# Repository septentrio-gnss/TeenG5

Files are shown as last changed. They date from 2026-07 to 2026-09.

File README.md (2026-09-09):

# TeenG5

<p align="center">
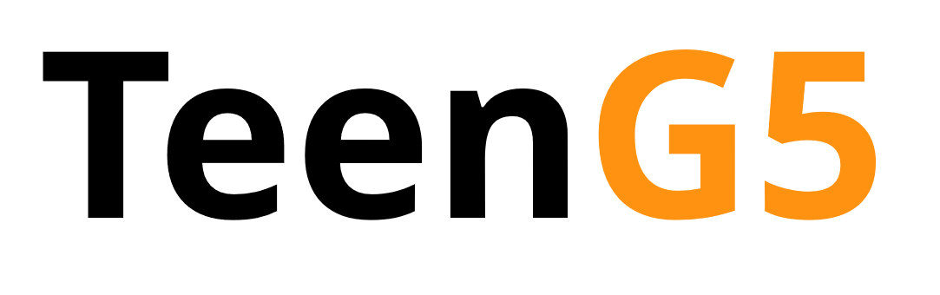
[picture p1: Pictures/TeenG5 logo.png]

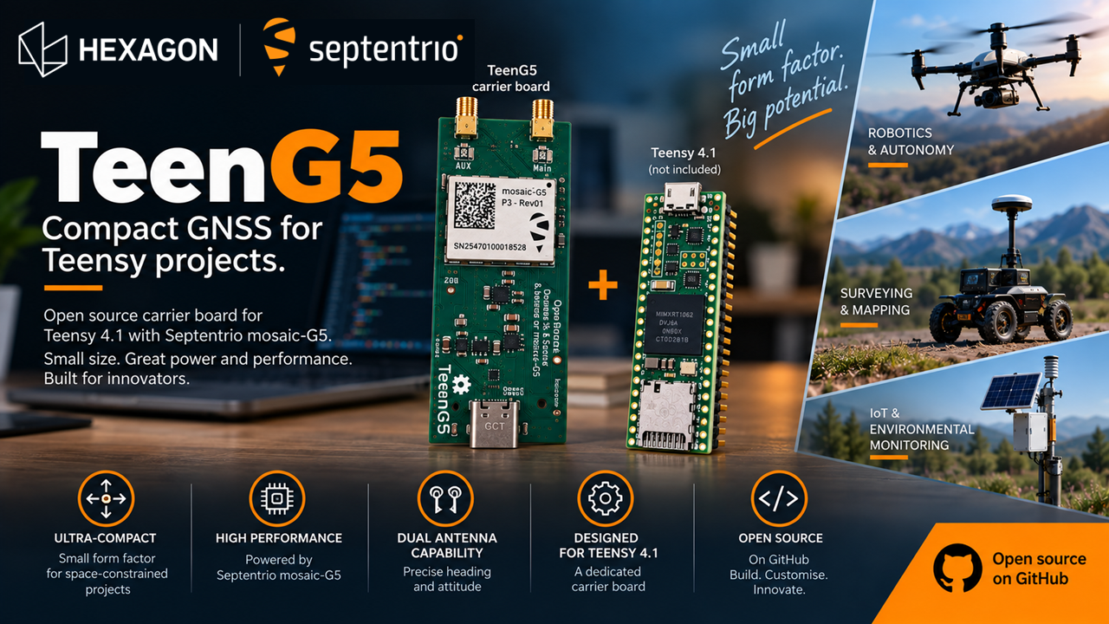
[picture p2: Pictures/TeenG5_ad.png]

</p>p

|TeenG5| Carrier board for Teensy 4.1|
|---|---|
|Author|  [laekaz](https://github.com/laekaz)|
|Maintainer| [Septentrio gnss github user](githubuser@septentrio.com)|
|external website| https://github.com/septentrio-gnss/TeenG5  |
|License| [CC BY-SA 4.0](https://creativecommons.org/licenses/by-sa/4.0/) and [open source](https://www.oshwa.org/definition/) |

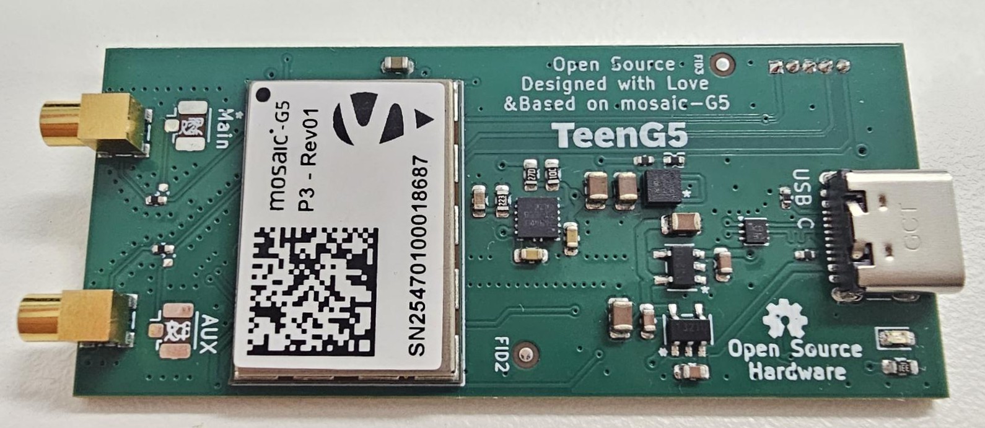
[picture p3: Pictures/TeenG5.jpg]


## Table of Content

* [What is TeenG5](#what-is-teeng5)
    * [What is the Teensy 4.1?](#what-is-the-teensy-41)
    * [What is a Carrier Board for Teensy 4.1?](#what-is-a-carrier-board-for-teensy-41)
    * [Produce Yourself?](#produce-yourself)
            * [Do I Need to Source Special Components for Producing This Board?](#do-i-need-to-source-special-components-for-producing-this-board)
    * [What is a mosaic-G5 Module?](#what-is-a-mosaic-g5-module)
        * [Other mosaic-G5 Versions](#other-mosaic-g5-versions)
    * [Who is Septentrio?](#who-is-septentrio)
    * [Deliverables](#deliverables)
    * [Is the Project Open-Source?](#is-the-project-open-source)
* [Disclaimer](#disclaimer)
* [Documentation Sections](#documentation-sections)

## What is TeenG5
This is a compact carrier board that brings high precision GNSS (GPS) which integrates mosaic-G5 Septentrio's GNSS module with basic communications, allowing the system to receive signals from multiple GNSS constellations, such as GPS, Galileo, GLONASS, and BeiDo. The goal of the design is to simplify hardware prototyping and integration of the mosaic-G5 by taking advantage of the [Teensy 4.1's](https://www.pjrc.com/store/teensy41.html) high-performance microcontroller, extensive peripheral interfaces, and Arduino-compatible development ecosystem. This makes TeenG5 well suited for embedded applications such as robotics, autonomous vehicles, UAVs, precision agriculture, surveying, timing, and other systems that require low-latency GNSS processing without relying on an external computer.
 
The board can also operate as a standalone device when powered through its USB connector.

### What is the Teensy 4.1?
The [Teensy 4.1](https://www.pjrc.com/store/teensy41.html) is a compact, high-performance microcontroller development board based on the NXP i.MX RT1062 ARM Cortex-M7 processor running at 600 MHz. It offers 1 MB of RAM, 8 MB of onboard flash memory, a microSD card slot, USB host and device capabilities, Ethernet, and a wide range of digital, analog, and communication interfaces (UART, SPI, I²C, and CAN). Compatible with the Arduino IDE through Teensyduino software, it is well suited for robotics, real-time control,embedded systems, audio processing, data acquisition, and other performance-critical applications.

### What is a carrier board for Teensy 4.1?
A carrier board is a board that hosts a removable Teensy 4.1. The Teensy plugs into the board through two 24-pin headers and can be removed or replaced, while the carrier board integrates the Septentrio mosaic-G5 GNSS receiver, power management, and communication interfaces into a single embedded platform.

### Produce yourself?
You can use the design files, Bill of Materials from this project and contact your manufacturing company for production. In this project we used [JLCPCB](https://jlcpcb.com/) for producing the PCB and assembling it. We used JLCPCB because of its competitive pricing and component availability.

##### Do I need to source special components for producing this board?

Yes, Some components are not available through JLCPCB's standard parts library and must be supplied separately. however, if you are assembling the PCB by yourself, all components are available on DigiKey and clearly listed in the project's Bill of Materials. The mosaic GNSS module can be obtained from Digikey or directly from Septentrio. For larger production volumes, we recommend contacting the Septentrio sales team directly at [Septentrio Contact Page](https://www.septentrio.com/en/contact/ask-question)

### What is a mosaic-G5 module?
The mosaic-G5 is a compact GNSS receiver from Septentrio, engineered for high reliability and precise positioning. It integrates the latest multi-band, multi-constellation GNSS technology, providing accurate positions while minimizing power consumption. The receiver can access signals from all major GNSS constellations, including GPS, Galileo, GLONASS, and BeiDou.

#### Other mosaic-G5 versions
Different versions of the mosaic-G5 are available to suit various applications, as summarized below:

| Features | [mosaic-G5 P1](https://www.septentrio.com/en/products/gnss-receivers/gnss-receiver-modules/mosaic-g5-p1) | [mosaic-G5 P3](https://www.septentrio.com/en/products/gnss-receivers/gnss-receiver-modules/mosaic-G5-P3) | [mosaic-G5 P3H](https://www.septentrio.com/en/products/gnss-receivers/gnss-receiver-modules/mosaic-G5-P3H) |[mosaic-G5 P6](https://www.septentrio.com/en/products/gnss-receivers/gnss-receiver-modules/mosaic-G5-P6) | [mosaic-G5 P8](https://www.septentrio.com/en/products/gnss-receivers/gnss-receiver-modules/mosaic-g5-p8) |
|---|---|---|---|---|---|
| Functionality|High-precision positioning |High-precision positioning |Positioning + Heading|Positioning + Heading | Positioning + Heading|
| Use case |Robotics (e.g robotic mowers), GIS devices |UAV, Commercial mowers, Industrial Robotics, Survey, Marine navigation | Marine navigation, Machine control, Autonomous vehicles,  Survey | Autonomous vehicles, Marine navigation, Machine control, Survey | High-end autonomous systems, Robotics, Marine navigation, Survey, Machine control | 
| GNSS bands | Triple-band  | Quad-band | Quad-band |Quad-band |Quad-band  |
| RTK support  | Yes | Yes | Yes |Yes |Yes |
| Dual antenna | No |  No | Yes |Yes |Yes |
| Heading | NO | No | Yes |Yes |Yes |

### Who is Septentrio?
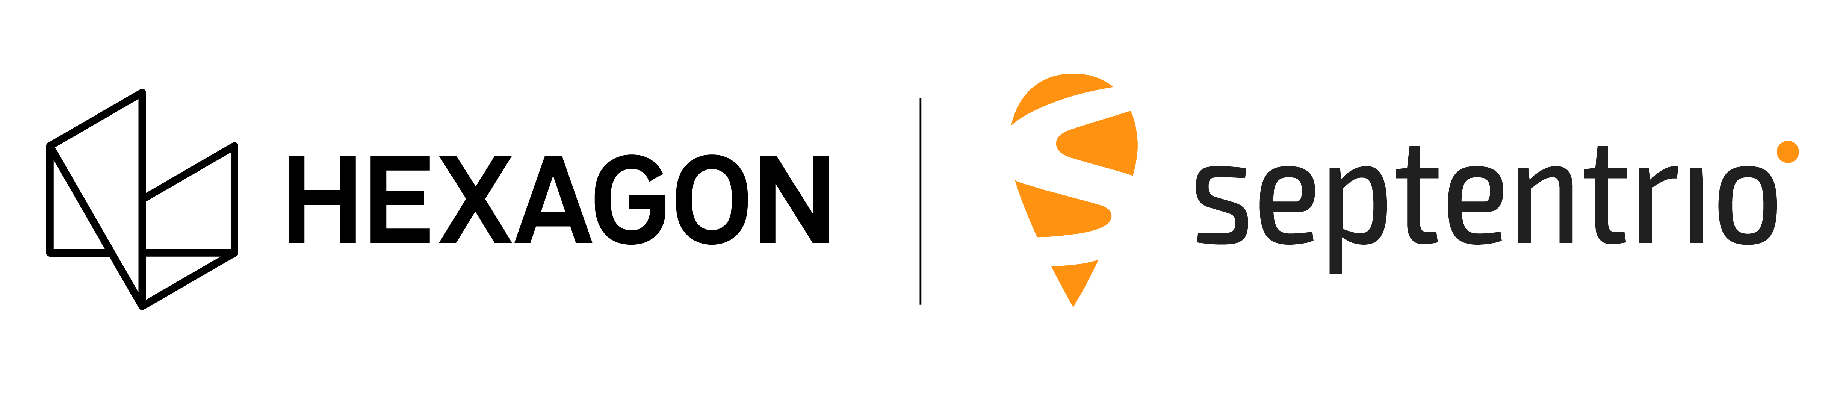
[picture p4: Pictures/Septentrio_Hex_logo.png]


Septentrio is a leading company that designs, manufactures and sells high precision and multi-frequency GPS/GNSS receivers for demanding applications. Septentrio products are used in different industries including automotive, marine, construction, rail, machine control, logistics, precision agriculture, geographic information systems (GIS), Unmanned aerial vehicles (UAVs), surveying, mapping and scientific development. Septentrio’s receivers constantly deliver accurate and precise GNSS positioning scalable to centimetre-level and designed to perform perfectly in challenging environments. 

Septentrio's technology offers high accuracy and reliability thanks to advanced GNSS signal-processing algorithms as well as [Advanced interference Monitoring and Mitigation (AIM+)](https://www.septentrio.com/en/learn-more/advanced-positioning-technology/aim-anti-jamming-protection) This protects your application against jamming (RF interference) and spoofing (malicious attacks).

For more information about Septentrio products go to [**https://www.septentrio.com/**](https://web.septentrio.com/GH-SSN-home).

### Deliverables
This project provides the following deliverables for system integrators and hardware designers developing solutions based on Septentrio's mosaic-G5 modules.

|Files |Description |
|---|---|
|  [G5_Teensy.kicad_pro](./Kicad/TeenG5/G5_Teensy.kicad_pro) |KiCad project |
| [G5_Teensy.kicad_pcb](./Kicad/TeenG5/G5_Teensy.kicad_pcb) | KiCad layout |
|  [G5_Teensy.kicad_sch](./Kicad/TeenG5/G5_Teensy.kicad_sch)  |KiCad schematic |
| [TeenG5 3D.step](./Kicad/TeenG5%203D/teenG5%203D.step) | TeenG5 3D|
| [mosaic-G5.STEP](./Kicad/mosaci-G5/mosaic-G5.STEP)  |mosaic-G5 3D |
| [LGA54_MOSAIC-MINI_SEP.kicad_mod](./Kicad/mosaci-G5/LGA54_MOSAIC-MINI_SEP.kicad_mod)  |mosaic-G5 footprint |
|  [BOM](./Kicad/BOM.xlsx) | TeenG5 Bill of Materials |
### Is the project open-source?
Yes, We made this open source so you can tinker, adapt, and create. If you are building your own robotics project, a spin-off device, or integrating GNSS into a larger system, this is a great starting point.

Open source here means:
* All files fully editable
* Freedom to modify, remix, and innovate
* You can sell your version. No -NC limitations
* May require attribution
* Build on our work, push it further, and even make money doing it

More info about licensing can be found here: [CC BY-SA 4.0](https://creativecommons.org/licenses/by-sa/4.0/) and [open source](https://www.oshwa.org/definition/)

## Disclaimer
This project is **offered as-is**. The main interfaces have been tested, but the design has not been fully checked or approved by the author or Septentrio. You are responsible for how you use it in your own projects. For guidance on working with Septentrio’s GNSS mosaic-G5 modules, we suggest reaching out to Septentrio directly.

Support website: https://www.septentrio.com/en/support
## Documentation Sections

This project provides two main documentation sections:

- **[TeenG5 User Documentation](./TeenG5%20User%20Documentation.md)**  
  Contains information for users on how to install, configure, and use the TeenG5.

- **[TeenG5 Design Documentation](./TeenG5%20Design%20Documentation.md)**  
  Intended for hardware designers who want to understand, customize, or modify the reference design of the TeenG5.

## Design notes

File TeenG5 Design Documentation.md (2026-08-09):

# TeenG5 Design Documentation

This section describes the design principles and architecture of the TeenG5 in depth.

## Table of Content

* [Design Overview](#design-overview)
* [mosaic-G5 Pinout](#mosaic-g5-pinout)
* [Power Sources](#power-sources)
* [Antennas](#antennas)
    * [Antenna Connectors](#antenna-connectors)
    * [First Antenna](#first-antenna)
    * [Second Antenna](#second-antenna)
* [Teensy 4.1 Serial](#teensy-41-serial)
* [Reset Input](#reset-input)
* [USB-C](#usb-c)
* [LEDs, Events and PPSO](#leds-events-and-ppso)
* [Clock Frequency Reference](#clock-frequency-reference)
* [Further Improvements](#further-improvements)

## Design Overview

The TeenG5 is a four-layer Printed Circuit Board (PCB) designed to mount directly a Teensy 4.1 onto it. The top and bottom layers are used for both signal and power routing. The first internal layer serves as a ground (GND) plane, while the first internal layer is primarily used as a 3.3 V power plane, with limited routing for additional connections where required.

The design as components on the **Top** and **bottom** side of the PCB board. The design uses Surface-Mount Devices (SMDs). throughout, except for the external connector.

The TeenG5 was designed using [KiCad](https://www.kicad.org/download/), an open-source Electronic Design Automation (EDA) suite. In addition to its schematic capture and PCB layout capabilities, KiCad includes an integrated 3D viewer that provides a realistic representation of the assembled board.

The schematic diagram is shown below. For improved readability and access to complete design details, refer to the PDF version of the [schematic]().

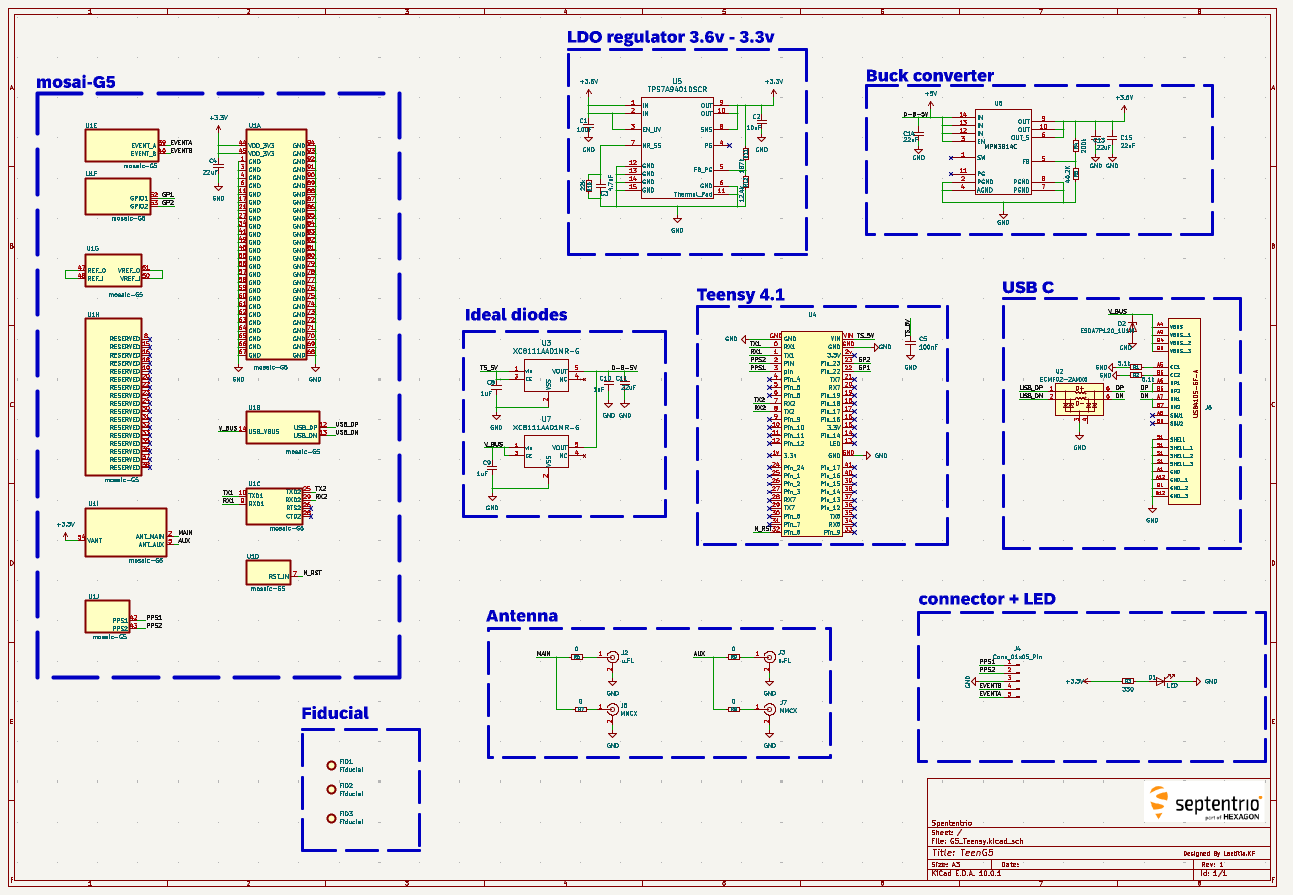
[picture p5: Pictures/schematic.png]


The board layout without the copper pour.

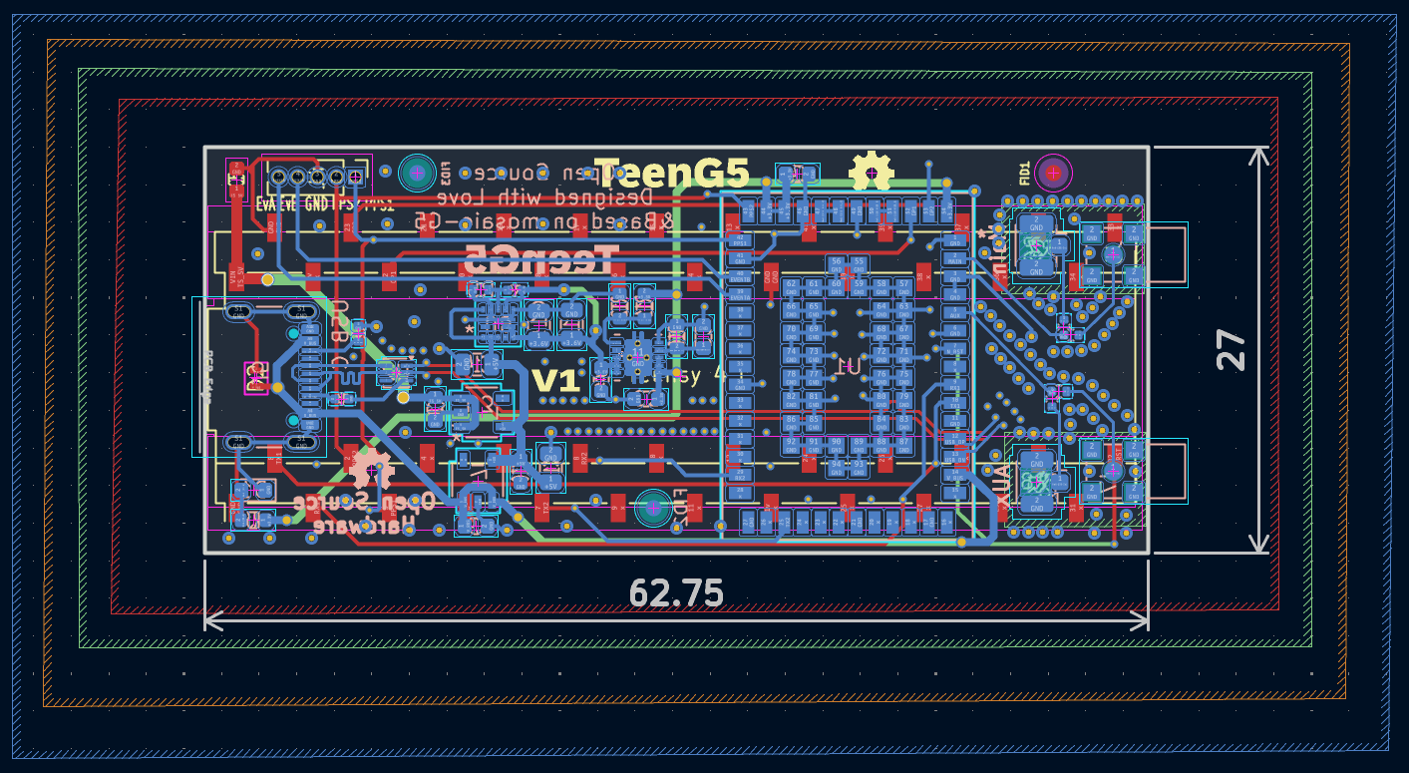
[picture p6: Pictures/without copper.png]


The board layout with the copper pour

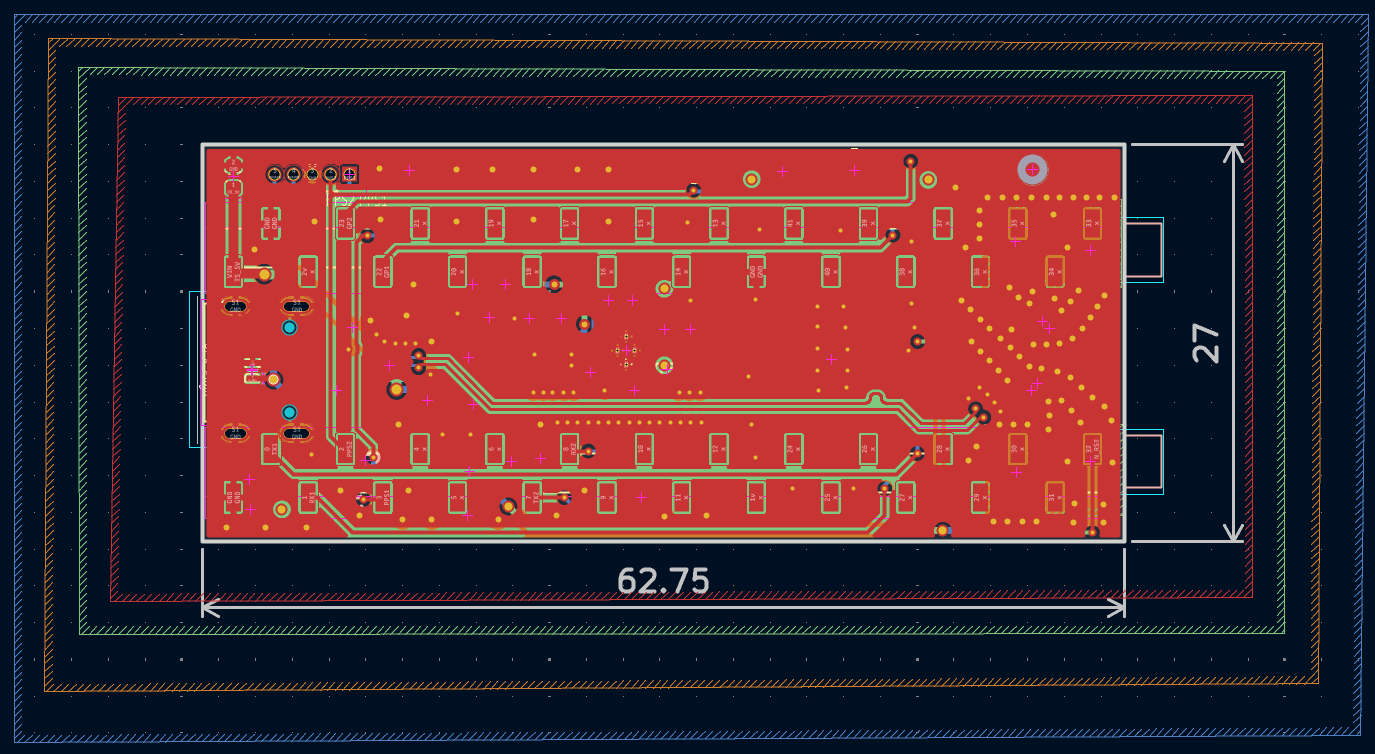
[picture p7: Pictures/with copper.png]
            

Layout layer descriptions:

|Layer|Description|
|---|---|
|Layer 1| Red traces, copper pour connected to GND |
|Layer 2| Green traces, copper pour connected to 3.3 V|
|Layer 3| Solid GND plane  |
|Layer 4| Blue traces, copper pour connected to GND|

A bottom and top 3D view of the TeeenG5, featuring electronic components.

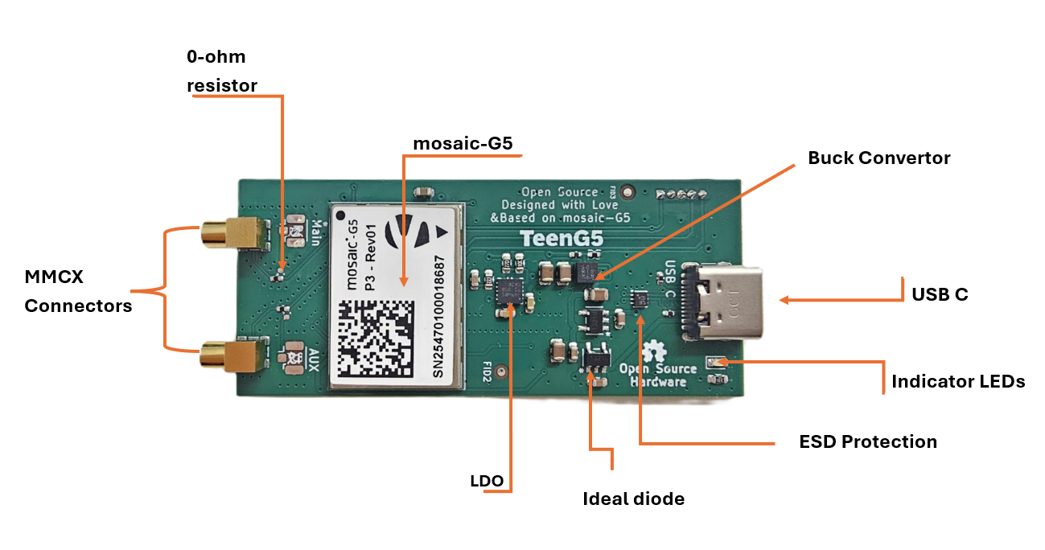
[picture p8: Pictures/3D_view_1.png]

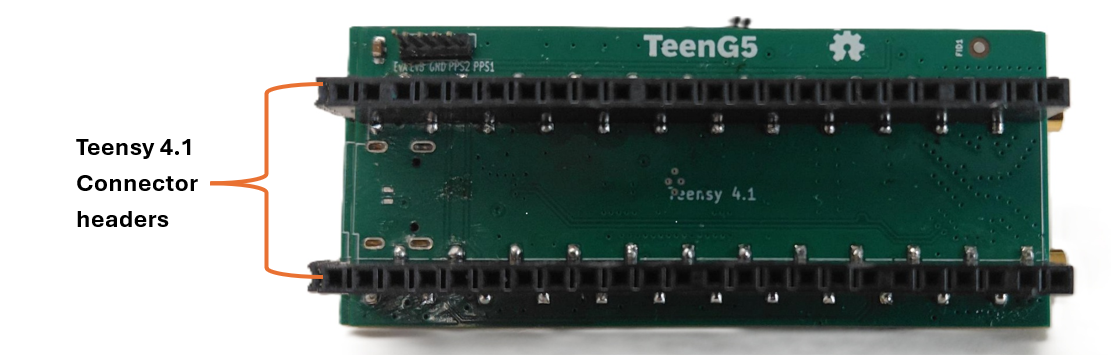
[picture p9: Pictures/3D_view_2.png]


## mosaic-G5 Pinout
The Septentrio mosaic-G5 is the core of the TeenG5 board. It is a 22.8 x 16.4 mm compact GNSS module of 94 pins with a weight of 2.2 g. Complete information on mosaic-G5 connections can be found in the [Hardware Manual](https://www.septentrio.com/en/products/gnss-receivers/gnss-receiver-modules/mosaic-G5-P3H).

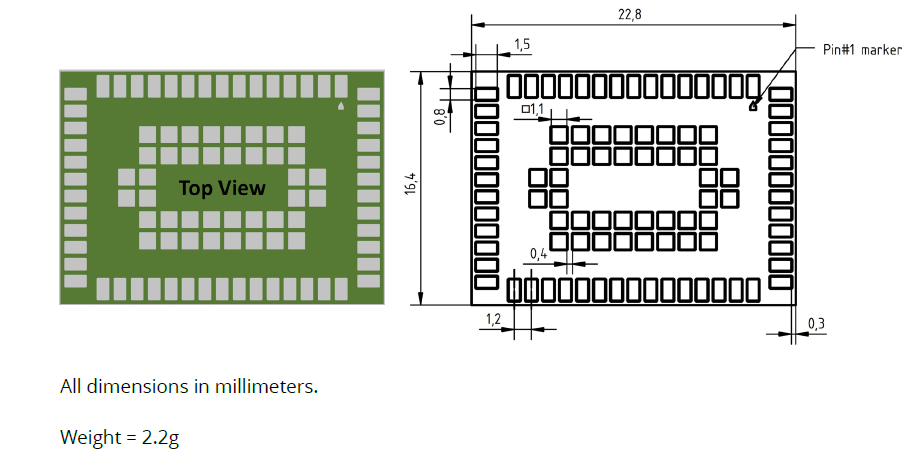
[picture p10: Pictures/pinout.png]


The symbol, footprint and 3D model of mosaic-G5 can be found [here](https://app.ultralibrarian.com/details/536b89de-4b22-11f0-b69d-024899f9dfe1/Septentrio/MOSAIC-G5-P3)

## power sources

The TeenG5 has 2 ways for powering the board; Teensy 4.1 VCC pin and USB-C. The mosaic-G5 module itself runs on 3.3V, thus a buck converter(MPM3814C) is used to regulate the voltage from 5V to 3.7V and an LDO voltage regulator is used to filter the switching noise from the buck converter and to regulate the voltage from 3.7 to 3.3volts(TPS7A9401DSCR). Teensy 4.1 VCC pin and USB-C already provide 5V.

 **WARNING:** Applying voltages higher than 5 V to the **VANT** may damage the module

The ideal diodes (**XC8111AA01MR-G**) are used to ensure one-way current flow. Decoupling capacitors (1 µF) are used according to the datasheet. The following figure shows the power section of the schematic.

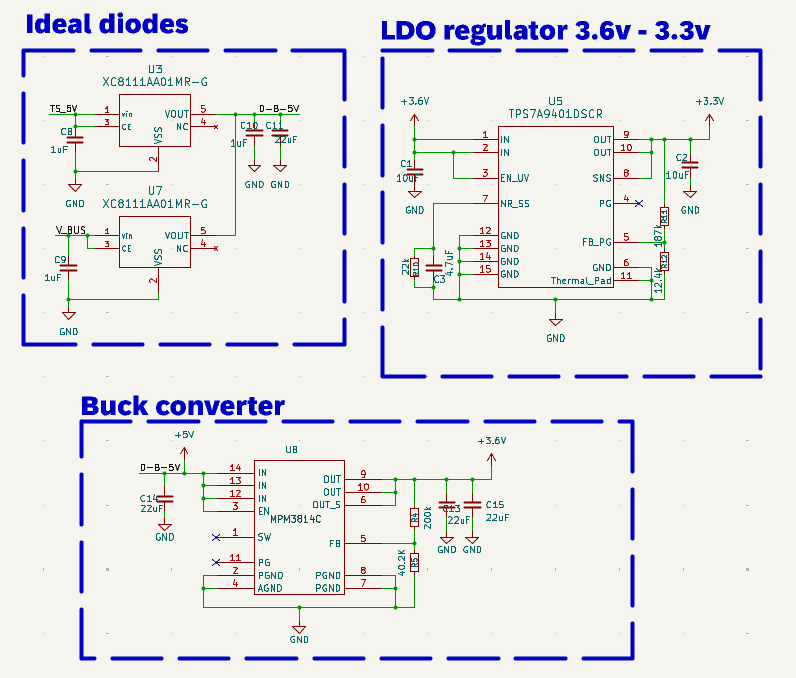
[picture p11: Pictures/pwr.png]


In the figure above:
1. Buck converter(MPM3814C).
2. Voltage regulator (TPS7A9401DSCR).
3. Teensy 4.1 power source (5V pins).
4. Micro USB power source.

## Antennas 
The mosaic-G5 P3H is a dual-antenna while the mosaic-G5 P3 is a single-antenna both of these modules are compatible with the PCB board however, when connecting the mosaic-G5 P3 you only connect the main antenna connector and leave the auxiliary unconnected. Both the antenna pins are not ESD-protected or biased in the schematics because all is done inside the module. 

The following figure shows the antenna section of the schematic.

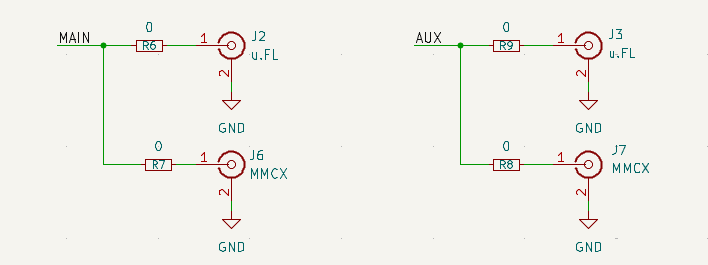
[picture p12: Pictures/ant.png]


### Antenna Connectors

### First Antenna

The first U.FL antenna J2 is directly connected to a 0 ohm resistor and the first MMCX antenna J6 is also connected to a 0 ohm resistor and they are both connected to the main mosaic-G5 pin.
The DC voltage of the main antenna connection is supplied from the mosaic-G5's VANT pin.

The input impedance of the RF line is 50 Ohms. Thus, antenna trace should have a characteristic impedance (Zo) of 50 Ohms. To determine the proper impedance for the antenna traces for RF signal routing, calculations were performed with the [JLCPCB Impedance Calculator](https://jlcpcb.com/pcb-impedance-calculator)(recommended if you are using JLCPCB as manufacturer) or can use freeware [Saturn PCB toolkit](https://saturnpcb.com/pcb_toolkit). The trace parameters used in the calculation were based on the specifications of the selected PCB manufacturer. Calculations determined that a trace width of 0.1725 mm would provide an impedance of 50Ω to the RF antenna traces.

Having right characteristic impedance ensures reduced signal reflections in the opposite direction thus higher quality of signals. For uniform lines, characteristic impedance is dependent on trace length.

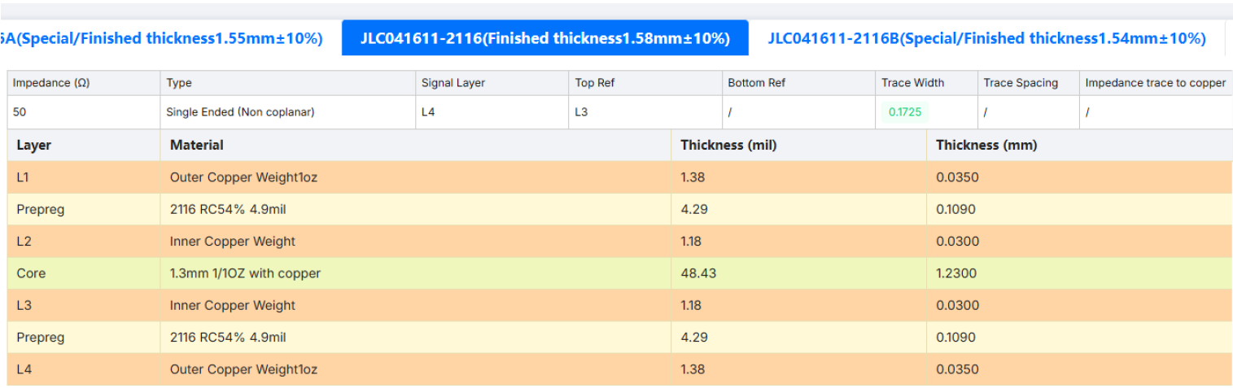
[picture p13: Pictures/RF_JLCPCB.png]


It is also important to stitch vias every few millimeters around the RF line for good ground coherence. Ground stitching vias help to protect line from interference.

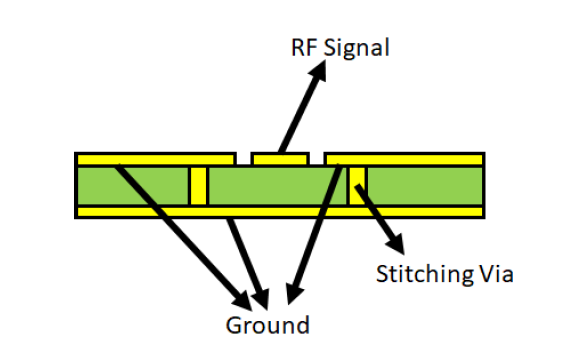
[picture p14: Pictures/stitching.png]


For more details on antennas and interference please refer to mosaic-G5's [Hardware Manual](https://www.septentrio.com/en/products/gnss-receivers?f%5B0%5D=type%3A604).

### second antenna

The second antenna is similar to the first antenna except when using a single antenna module like the mosaic-G5 P3, you do not need to assemble the the second antenna connector. 

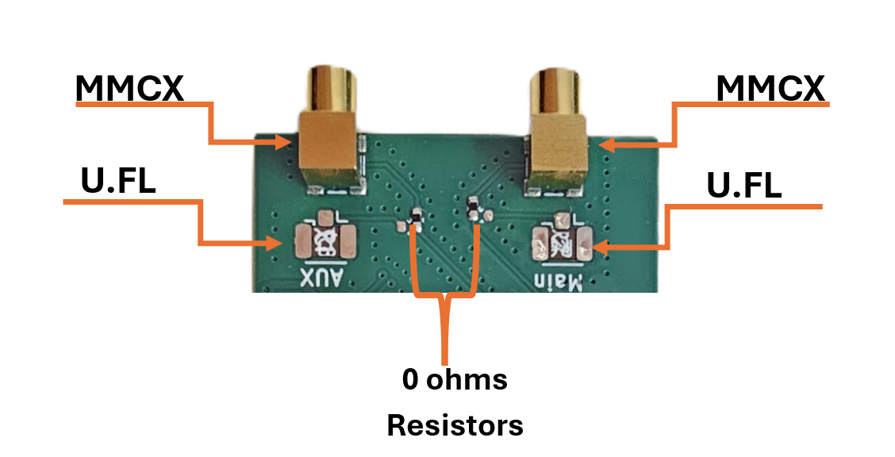
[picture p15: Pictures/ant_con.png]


## Teensy 4.1 serial

Serial communication between the mosaic-G5 and the Teensy 4.1 is implemented by connecting UART1 and UART2 connections of mosaic-G5 to Teensy 4.1 UART pins: TX (Pin 0, Pin 1) and RX (Pin 7, Pin 8). The mosaic-G5's TX is connected to the Teensy 4.1's RX while RX is connected to Teensy 4.1's TX for both UARTs.

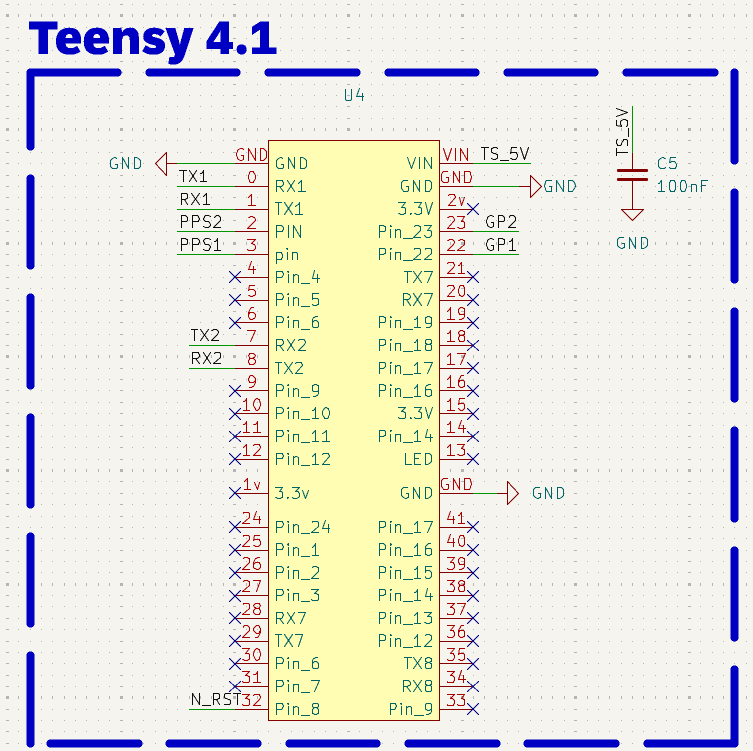
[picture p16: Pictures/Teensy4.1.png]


## Reset Input
The N_RST pin of mosaic-G5 is directly connected to Teensy 4.1 (Pin 32 in physical header). Refer to [Reset mosaic](#reset-mosaic-G5) in user documentation for more details.

## USB-C
To use mosaic-G5 as a USB device, the following pins of the module should be connected to a USB-C connector:



A common mode filter with ESD protection for USB 2.0 (ECMF02-2AMX6) is used with USB_DP (D+) and USB_DN (D-) for protection. The filter suppresses electromagnetic interference (EMI) on high-speed differential USB lines.

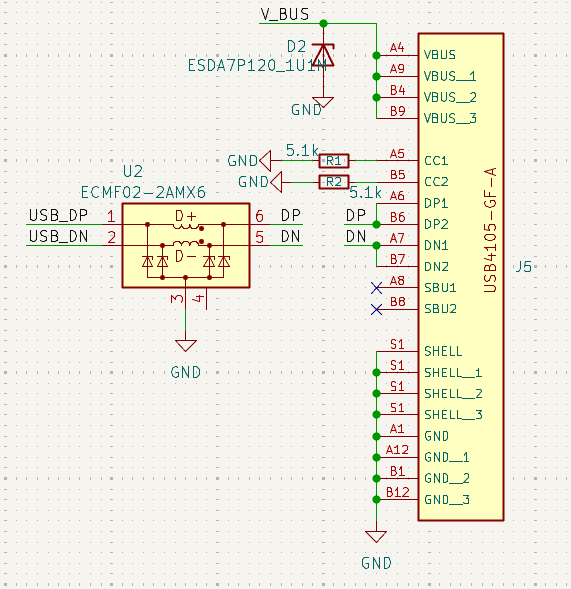
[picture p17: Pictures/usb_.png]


As USB uses a differential pair for data transmission, differential pair impedance (Zdifferential) should be tuned to avoid reflections. Zdifferential needs to be around 90 Ohms. The same [JLCPCB impedance calculator](https://jlcpcb.com/pcb-impedance-calculator) was used to determine the dimensions of the differential signal pair that will carry the USB signals. 

The parameters used for this calculation were the same as those used for the RF antenna traces: the materials, thickness of copper finish, and number of layers of the PCB manufacturer that was selected. The results of this calculation determined that a width of 0.1707 mm would provide the necessary impedance of 90 Ω to the differential signal pair. 

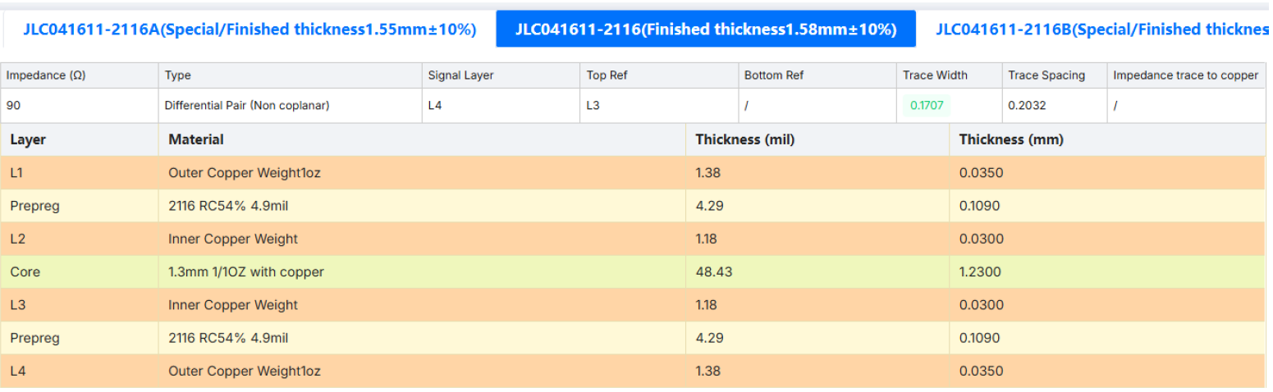
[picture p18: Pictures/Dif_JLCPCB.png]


The following figure hights USB parts highlighted. GND vias were stitched around the USB connector and lines to ensure good ground coherence.

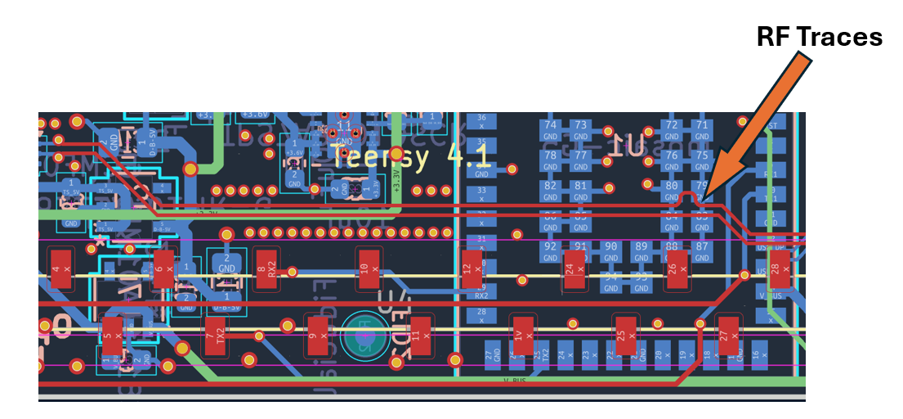
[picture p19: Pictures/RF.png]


* USB-C connector (USB4105-GF-A).
* Common mode filter.
* USB D+/D- lines.
* VBUS.

## LEDs,Events and PPSO

TeenG5 has 1 LED which is a power indicator.

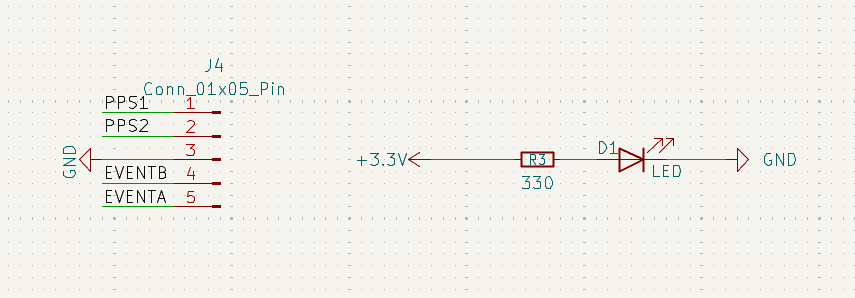
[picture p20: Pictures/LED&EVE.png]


## Clock Frequency Reference
mosaic-G5 module embeds an internal Temperature Compensated Crystal Oscillator (TCXO) for frequency reference. The module can either use its internal TCXO frequency reference or an external frequency reference. In TeenG5's case, internal reference is used.

Following are Hardware Manual instructions for using internal TCXO.



Layout connections for REF and VREF_I.

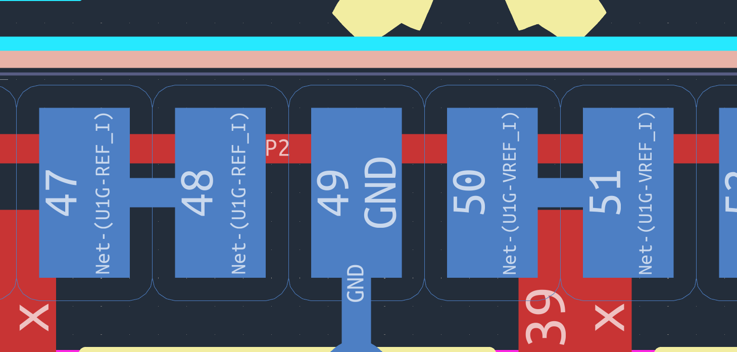
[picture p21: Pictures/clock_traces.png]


## Further improvements

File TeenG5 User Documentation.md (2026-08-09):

# TeenG5 user documentation
## Table of Content
* [TeenG5 Manufacturing and Assembly](#teeng5-manufacturing-and-assembly)
    * [Elements to Provide When Manufacturing the Board](#elements-to-provide-when-manufacturing-the-board)
    * [Ordering mosaic Module](#ordering-mosaic-module)
* [General Interfaces of TeenG5](#general-interfaces-of-teeng5)
* [Connecting to Teensy 4.1](#connecting-to-teensy-41)
    * [Preparing Teensy 4.1](#preparing-teensy-41)
    * [Arduino Example](#arduino-example)
    * [GNSS Antenna](#gnss-antenna)
        * [Single/Dual Antenna Mode](#singledual-antenna-mode)
        * [Heading](#heading)
    * [USB Communication](#usb-communication)
    * [Serial Communication](#serial-communication)
    * [Reset mosaic-G5](#reset-mosaic-g5)
    * [PPS Output](#pps-output)
    * [Events](#events)

## TeenG5 Manufacturing and Assembly

This project includes all the files required to manufacture the TeenG5, including the reference design, PCB layout, and Bill of Materials (BOM). You can use these files with your preferred PCB manufacturer. For this project, we used [JLCPCB](https://jlcpcb.com/) for both PCB fabrication and assembly due to their competitive pricing and fast production times.

### Elements to provide when manufacturing the board
When you manufacture your board they will ask you for the following parts:

For the PCB only:
* The PCB design, you will need to export gerber and drill files 

For assembly:
* Bill of Materials (BOM), the list of components used in the project with their reference designators. For this project check [BOM](/Kicad/BOM.xlsx).
* Component Placement List (CPL), this file contains the exact position of each component on the board (X,Y and rotation). CPL is exported from KiCad however, you need to check with the manufacturer services to ensure the right placement for components.

### Ordering mosaic module
You can order the mosaic-G5 from Digi-Key, or you can contact Septentrio at www.septentrio.com for purchasing inquiries or other mosaic models.

| mosaic-G5 versions | Septentrio | Digi-Key part_number|
|---|---|---|
| mosaic-G5 P1 |[Septentrio_G5-P1](https://www.septentrio.com/en/products/gnss-receivers/gnss-receiver-modules/mosaic-g5-p1) | - |
| mosaic-G5 P3 | [Septentrio_G5-P3](https://www.septentrio.com/en/products/gnss-receivers/gnss-receiver-modules/mosaic-G5-P3) | [410501](https://www.digikey.com/en/products/detail/septentrio-inc/410501/28527327) |
| mosaic-G5 P3H |[Septentrio_G5-P3H](https://www.septentrio.com/en/products/gnss-receivers/gnss-receiver-modules/mosaic-G5-P3H) | [410502](https://www.digikey.com/en/products/detail/septentrio-inc/410502/28527213) |
| mosaic-G5 P6 |[Septentrio_G5-P6](https://www.septentrio.com/en/products/gnss-receivers/gnss-receiver-modules/mosaic-G5-P6) | - |
| mosaic-G5 P8 |[Septentrio_G5-P8](https://www.septentrio.com/en/products/gnss-receivers/gnss-receiver-modules/mosaic-g5-p8) | - |

## General interfaces of TeenG5
The board exposes the following interfaces:

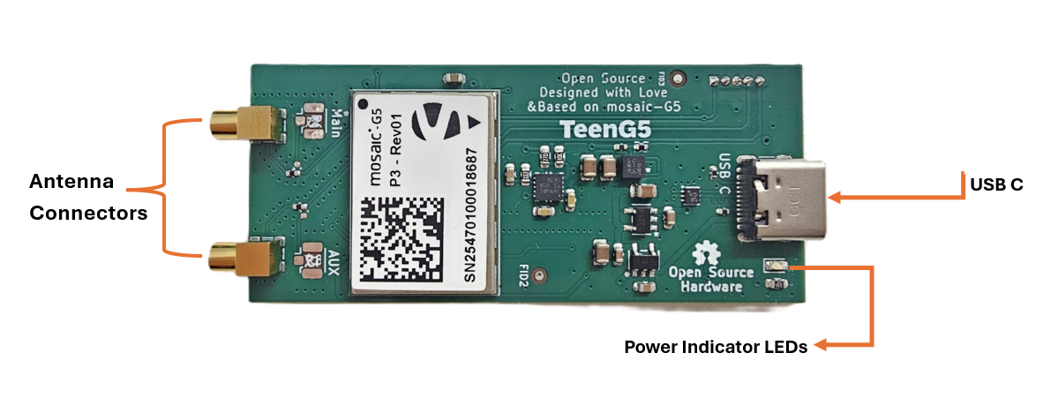
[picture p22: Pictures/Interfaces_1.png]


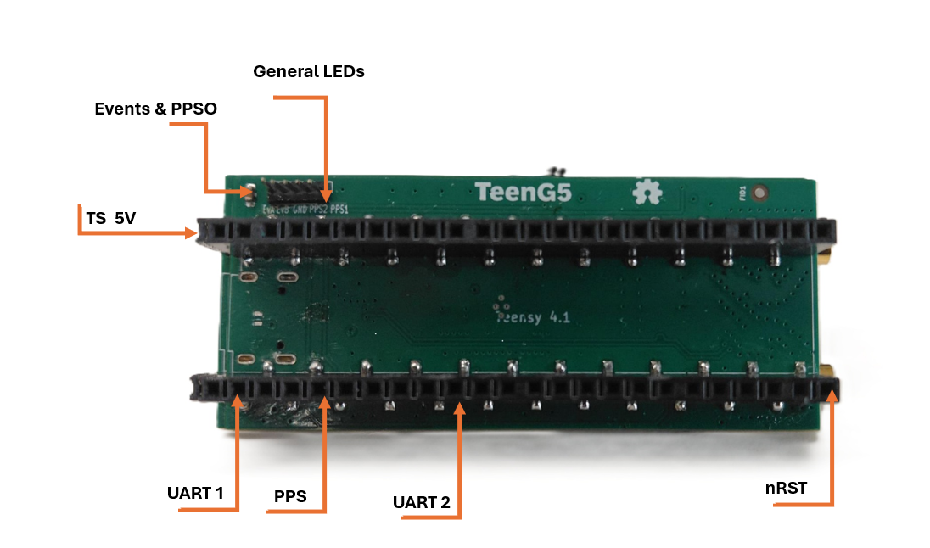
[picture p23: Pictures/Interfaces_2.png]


## Connecting to Teensy 4.1
Teensy 4.1 can be easily attached to TeenG5 as shown here:

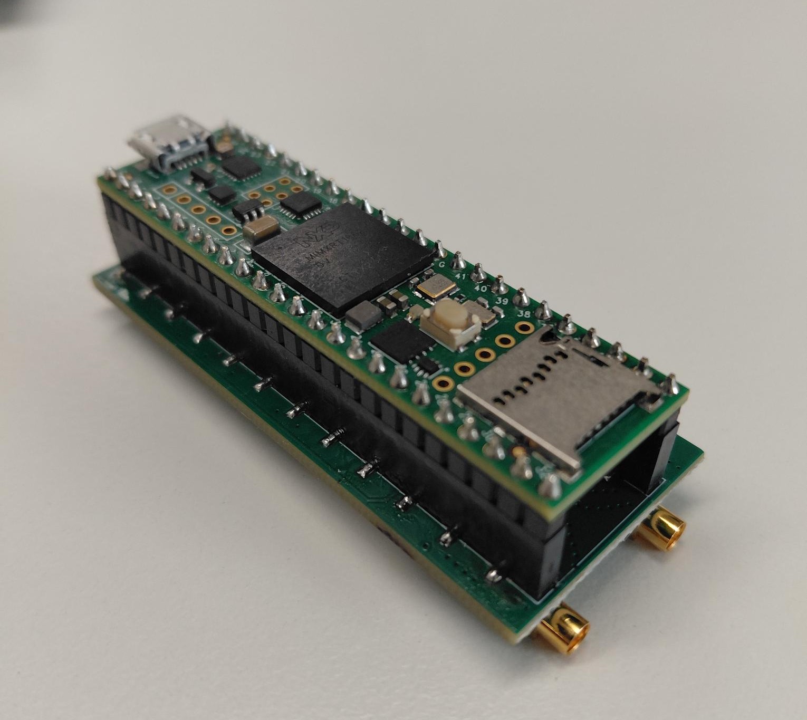
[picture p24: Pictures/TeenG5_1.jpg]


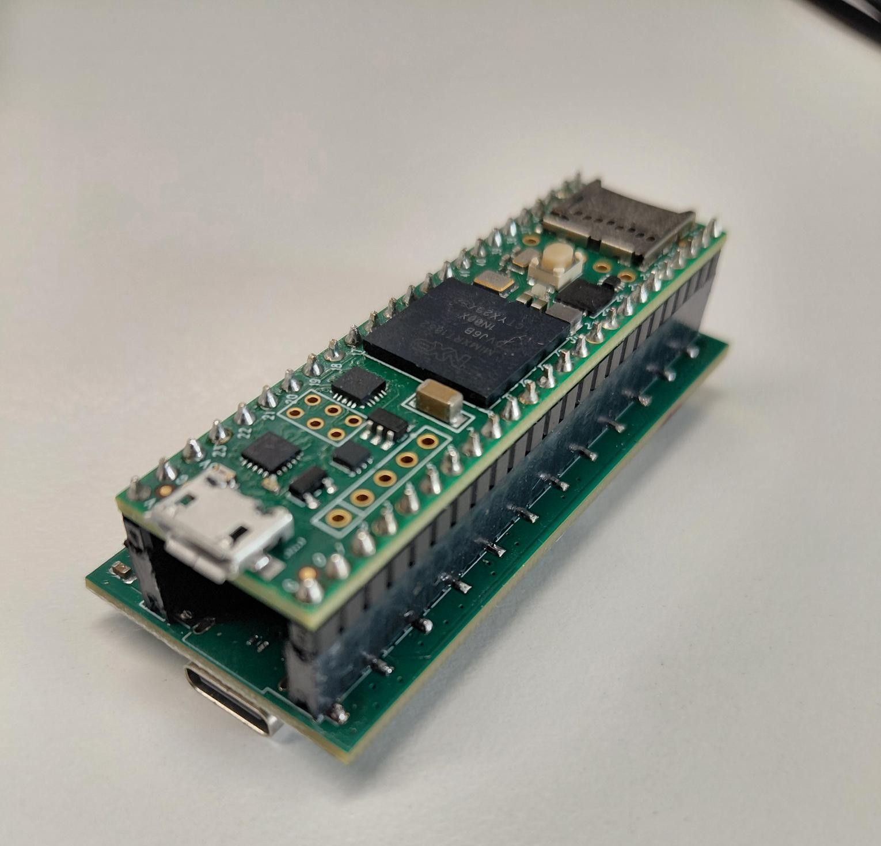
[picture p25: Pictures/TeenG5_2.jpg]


### Preparing Teensy 4.1
Arduino IDE was used to promgram the TeenG5 and Teensy 4.1

To enable communication between TeenG5 and Teensy 4.1, you should make sure required settings configured:

* Pick the correct board,



* pick USB serial,



* and pick the correct serial COM port.

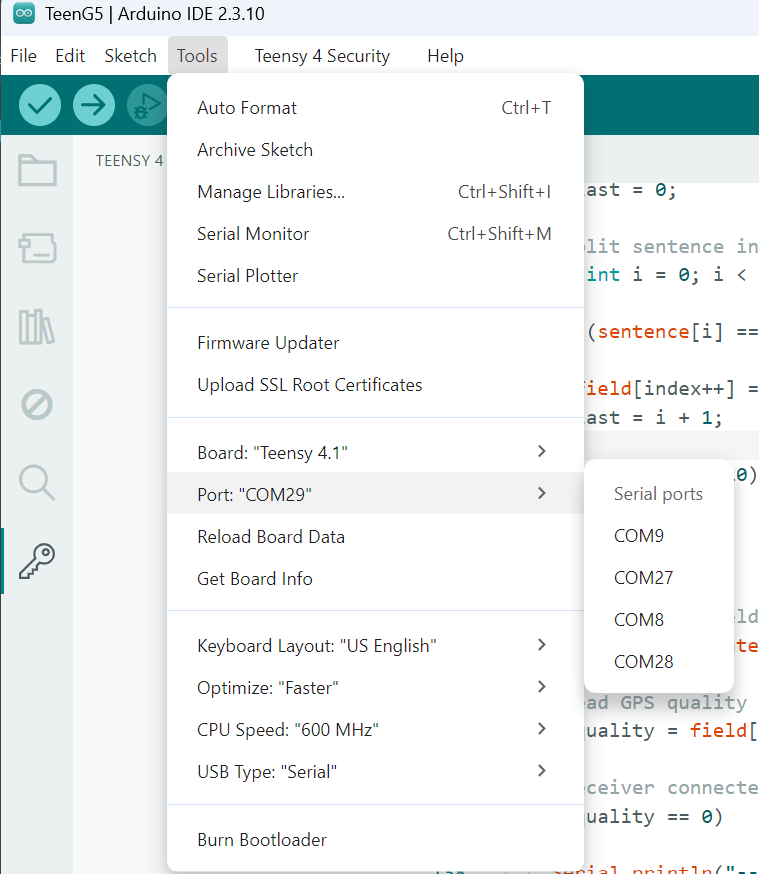
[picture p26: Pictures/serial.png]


### Arduino Example

```
// Stores one complete NMEA sentence
String nmeaSentence;

// Time when the last character was received
unsigned long lastReceiveTime = 0;

// Keeps track of whether the receiver is currently missing
bool receiverMissing = true;

void setup()
{
  // Start USB serial communication
  Serial.begin(115200);

  // Wait for the Serial Monitor (maximum 5 seconds)
  while (!Serial && millis() < 5000);

  // Start communication with the GNSS receiver
  Serial1.begin(115200);

  // Allow the receiver to boot
  delay(1000);

  // Send several 'S' characters to enter command mode
  Serial1.print("SSSSSSSSSSSSSS\n");
  delay(100);

  // Enable GGA messages every second
  Serial1.print("sno, Stream1, COM1, GGA, sec1\n");
  delay(100);

  Serial.println();
  Serial.println("GNSS Monitor Started");
  Serial.println("--------------------");
}

void loop()
{
  // Read all available serial characters
  while (Serial1.available())
  {
    // Receiver is present
    receiverMissing = false;

    // Remember when the latest data arrived
    lastReceiveTime = millis();

    // Read one character
    char c = Serial1.read();

    // Ignore carriage returns
    if (c == '\r')
      continue;

    // Complete sentence received
    if (c == '\n')
    {
      processGGA(nmeaSentence);

      // Clear buffer for next sentence
      nmeaSentence = "";
    }
    else
    {
      // Build the NMEA sentence
      nmeaSentence += c;
    }
  }

  // No serial data received for more than 3 seconds
  if (millis() - lastReceiveTime > 3000)
  {
    if (!receiverMissing)
    {
      Serial.println("--------------------------------");
      Serial.println("No Receiver Detected");
      Serial.println("--------------------------------");
      Serial.println();

      receiverMissing = true;
    }
  }
}

//----------------------------------------------------
// Process GGA sentence
//----------------------------------------------------
void processGGA(String sentence)
{
  // Ignore sentences that are not GGA
  if (!(sentence.startsWith("$GNGGA") ||
        sentence.startsWith("$GPGGA")))
    return;

  // Array to store the comma-separated fields
  String field[20];

  int index = 0;
  int last = 0;

  // Split sentence into fields
  for (int i = 0; i < sentence.length(); i++)
  {
    if (sentence[i] == ',')
    {
      field[index++] = sentence.substring(last, i);
      last = i + 1;

      if (index >= 20)
        break;
    }
  }

  // Store final field
  field[index] = sentence.substring(last);

  // Read GPS quality indicator
  int quality = field[6].toInt();

  // Receiver connected but no valid position
  if (quality == 0)
  {
    Serial.println("--------------------------------");
    Serial.println("No Position");
    Serial.print("Quality Indicator: ");
    Serial.println(quality);
    Serial.println();

    return;
  } else{

    // Read UTC time
      String utc = field[1];

      // Read latitude (NMEA format)
      float latitude = field[2].toFloat();
      String latDir = field[3];

      // Read longitude (NMEA format)
      float longitude = field[4].toFloat();
      String lonDir = field[5];

      // Read altitude
      float altitude = field[9].toFloat();
      String altitudeUnit = field[10];

      // Display results
      Serial.println("--------------------------------");

      Serial.print("UTC Time: ");
      Serial.println(utc);

      Serial.print("Latitude: ");
      Serial.print(latitude, 4);
      Serial.print(" ");
      Serial.println(latDir);

      Serial.print("Longitude: ");
      Serial.print(longitude, 4);
      Serial.print(" ");
      Serial.println(lonDir);

      Serial.print("Altitude: ");
      Serial.print(altitude);
      Serial.print(" ");
      Serial.println(altitudeUnit);

      Serial.print("Quality Indicator: ");
      Serial.println(quality);

  }

  Serial.println();
}

```

### GNSS Antenna

To take full advantage of the multi-band and multi-constellation capabilities of the TeenG5, it is recommended to use a high-quality multi-band GNSS antenna.

Several manufacturers offer suitable GNSS antennas, including Maxtena and Tallysman. You can also contact Septentrio for guidance on selecting an antenna that best fits your application.

GNSS antennas are available in different form factors and performance levels, each designed for specific use cases such as robotics, precision agriculture, surveying, or industrial machinery. While larger antennas often provide better performance due to improved antenna design and larger ground planes, antenna quality and internal element design are equally important factors. Selecting the right antenna for your application will have a significant impact on positioning accuracy and reliability.

For testing the board we used Tallysman antenna:

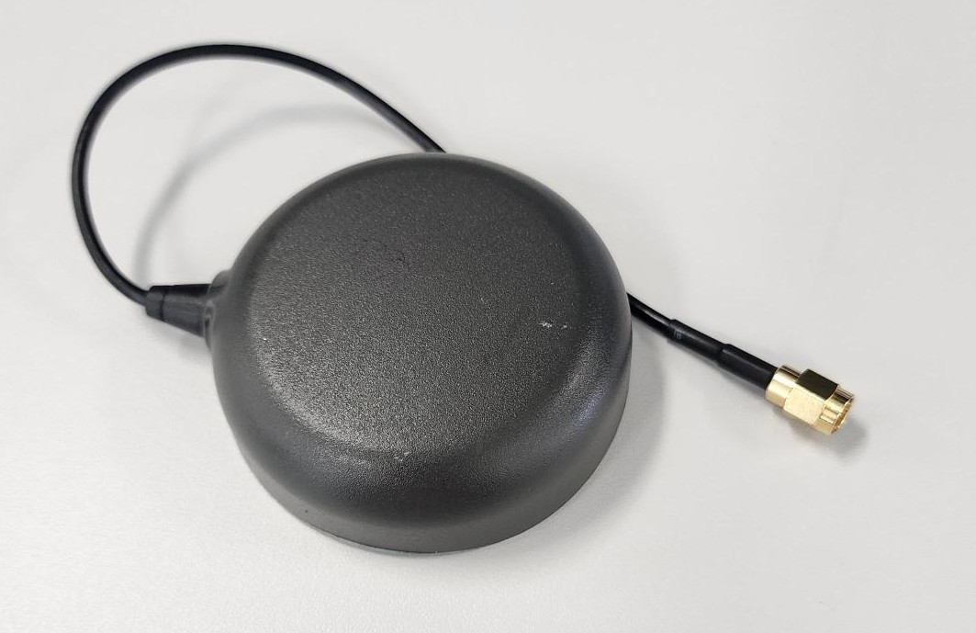
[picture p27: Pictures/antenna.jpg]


**NOTE**: The VANT (Antenna voltage) pad of mosaic-G5 module is directly connected to the 5 Volts after the ideal diodes so the power is from the Vin of the Teensy 4.1 or VBUS. The internal bias control circuit detects overcurrent
conditions (>150mA) and protects the module in case of short circuit. According to mosaic-G5 hardware manual, VANT accepts **3V** to **5.5V** power supply.

#### Single/Dual Antenna Mode

The receiver can operate in either **single-antenna** or **dual-antenna** mode. Changing the frontend mode only takes effect after a reboot.

* **Single-antenna mode**

Run:

```
setFrontendMode, SingleAnt
```
to configure the receiver for single-antenna mode at the next reboot.

Then save the configuration:

```
exeCopyConfigFile, Current, Boot
```

Finally, reboot the receiver:

```
exeResetReceiver, Hard, none
```

* **Dual-antenna mode**
Run:

```
setFrontendMode, DualAnt
```
to configure the receiver for dual-antenna mode at the next reboot.

Then save the configuration:

```
exeCopyConfigFile, Current, Boot
```
Finally, reboot the receiver:

```
exeResetReceiver, Hard, none
```
P3H, P6 and P8 can run both in single or dual mode deppending on how you configure it. connect both the antenner connectors when using dual mode. 

#### Heading

You can use mosaic-G5 P3H for heading but **it's essential to connect the two antenna connectors.** 

RxTools can be used to monitor the heading.

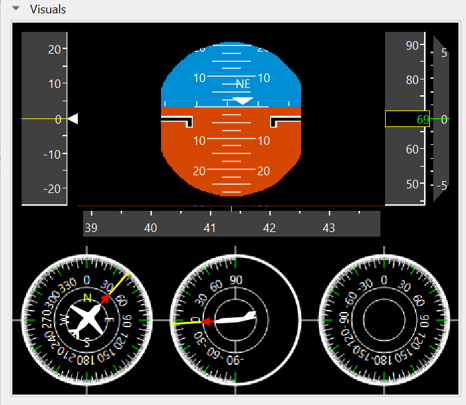
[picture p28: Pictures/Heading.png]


### USB communication

The TeenG5 via USB, provides 2 USB serial ports that can be used with [Septentrio's RxTools](https://www.septentrio.com/en/products/gps-gnss-receiver-software/rxtools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).

Septentrio's RxTools is a Software which can be used to communicate to the TeenG5 and can be downloaded free of charge from the [Septentrio support site](https://www.septentrio.com/en/products/gps-gnss-receiver-software/rxtools#resources). Once you have downloaded it you can use Septentrio's RxControl and Data Link which can communicate with the receiver over a serial-port connection: select Serial Connection option when opening the connection to the receiver.



**NOTE:** That currently there's no RxTools release for RPi (ARM architecture). Thus, RxTools should be used on a regular PC.

### Serial communication
A simple way to communicate with the mosaic-G5 receiver is to connect one of the UART, it offers 2 UARTs connections.

* Both UART connections are  connected to the Teensy 4.1 for easie integration.

Default COM-Port settings are:
|Parameter |Value |
|---|---|
|baud rate | 115200 | 
|data bits | 8 |
|parity |no |
|stop bits | 1 |
|flow control | none|

Can use comment ```sno, Stream1, COM2, GGA, sec1``` to output GGA data on the UART2

### Reset mosaic-G5

mosaic-G5 could be forced to reset from Teensy 4.1. The N_RST pin of mosaic-G5 is directly connected to Pin 34 in physical header.

The N_RST pin is active negative, which means mosaic will be in RESET mode when N_RST is low (GND). The pin is internally debounced (pull-up) so if pin is left unconnected (floating) the module will not enter RESET mode.

Initially, the Teensy 4.1 GPIO pins are set to INPUT mode. As the Teensy 4.1 input line have high impedance, N_RST will be floating. This means TeenG5 board could run without issues initially even if Pin 34 is not set to HIGH (while kept in input mode). However, it is not recommended to rely on the GPIO initial state. Users should drive HIGH to Pin 34 for the stability of their applications.

To reset module, a LOW pulse, not shorter than 1 microsecond, should be driven to Teensy 4.1.

### PPS output

PPS signals are used for precise timekeeping and time measurement. One increasingly common use is in time synchronization with other sensors (e.g. Lidars or IMUs).

The receiver is able to generate an x-pulse-per-second (xPPS) signal aligned with GPS, Galileo, GLONASS system time, UTC, or with the internal receiver time (RxClock). 

Polarity, frequency and pulse width of PPSO could be configured by **setPPSParameters** command.



By default, **PPSO2 is disabled**. It can be enabled and configured in **RxControl**:.





Both PPS Output operate at 3.3 V logic levels. PPSO1 and PPSO2 are directly connected to Teensy 4.1 GPIOs. 

More information on the definition of PPS output or on how to configure the PPS parameters can be found in the mosaic-G5 reference guide. You can download this one from [Septentrio site](https://www.septentrio.com/en/products/gnss-receivers/gnss-receiver-modules/mosaic-G5-P3H).

### Events
EVENTs could be tested directly on TeenG5 board by connecting PPS Output to one of the EVENTs pins. Note that this works with a single wire because they share the same GND. Here PPSO_1 is connected to EVENTB, with PPS interval set to 1 sec.




To monitor Events you could use Rxcontrol, clicking on the expert console. Once you have connected an output to the event pin you will see the data being recieved on the pin.

**Note:** The **EVENT** inputs use **3.3 V logic levels**. Applying higher voltages may damage the receiver.

For more information about the EVENT input functionality, see the **mosaic-G5 Reference Guide**, available from the [Septentrio website](https://www.septentrio.com/en/products/gnss-receivers/gnss-receiver-modules/mosaic-G5-P3H).

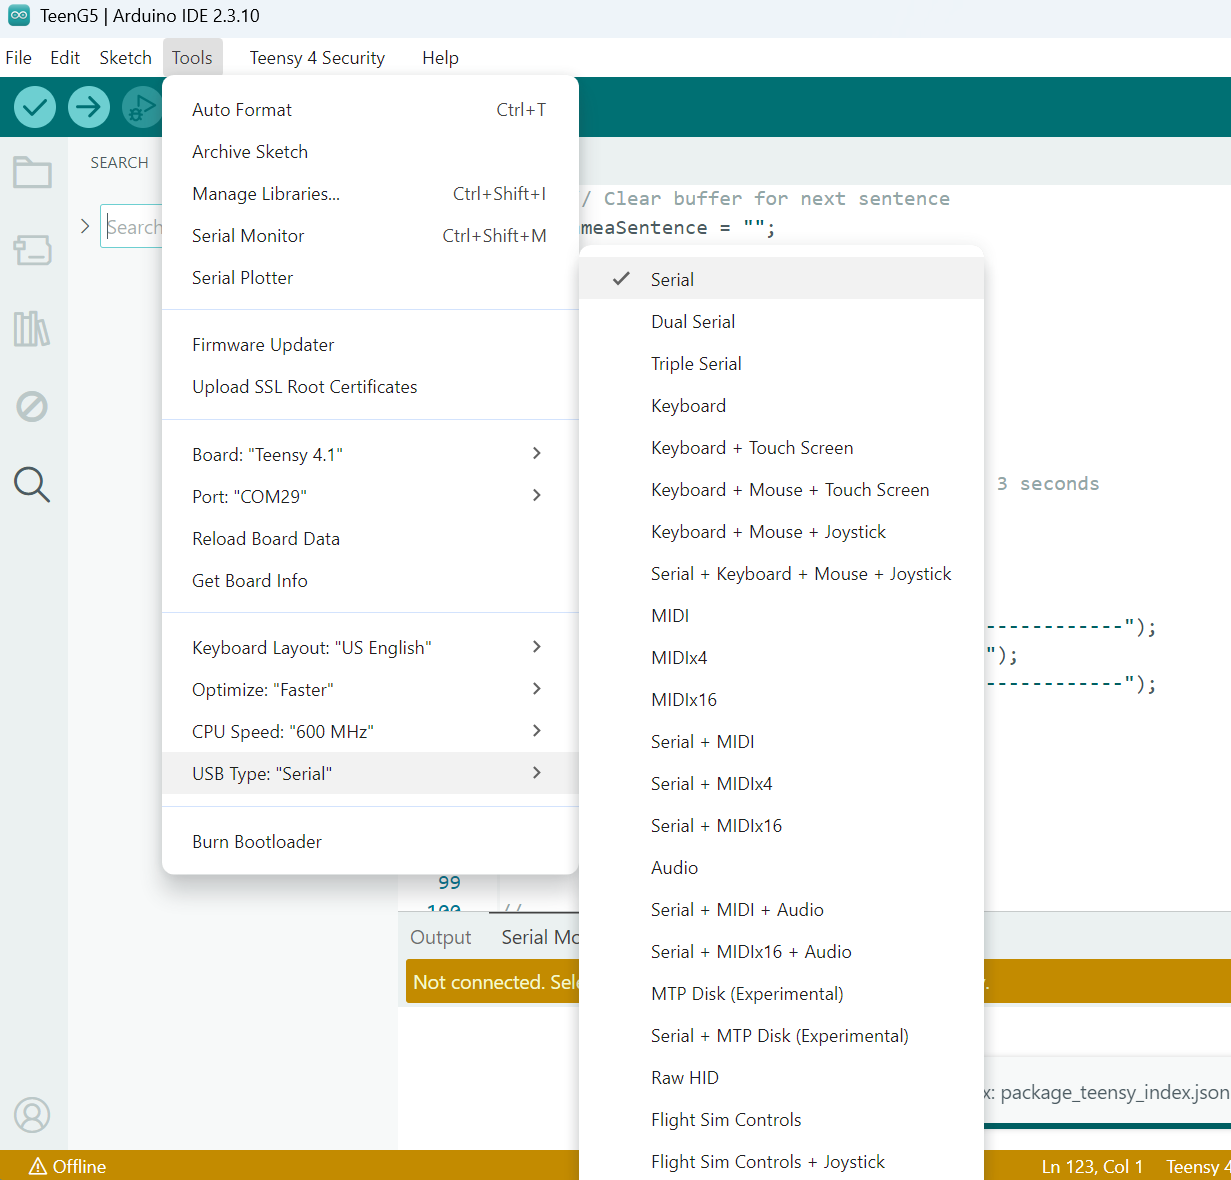
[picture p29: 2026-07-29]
Pictures/USB_serial.png

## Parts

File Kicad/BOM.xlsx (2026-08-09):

Designator | Value | Package | JLCPCB Parts | Quantity
C1 | 10uF | C_0603_1608Metric | C22399626 | 1
C2 | 10uF | C_0603_1608Metric | C22399626 | 1
C3 | 4.7uF | C_0603_1608Metric | C1705 | 1
C4 | 22uF | C_0603_1608Metric | C109447 | 1
C5 | 100nF | C_0603_1608Metric | C108079 | 1
C8 | 1uF | C_0603_1608Metric | C106248 | 1
C9 | 1uF | C_0603_1608Metric | C106248 | 1
C10 | 1uF | C_0603_1608Metric | C106248 | 1
C11 | 22uF | C_0805_2012Metric | C23692981 | 1
C13 | 22uF | C_0805_2012Metric | C23692981 | 1
C14 | 22uF | C_0805_2012Metric | C23692981 | 1
C15 | 22uF | C_0805_2012Metric | C23692981 | 1
D1 | LED | LED_0603_1608Metric | C440514 | 1
D2 | ESDA7P120_1U1M | ESD_ESDA7P120-1U1M | C2969802 | 1
J2 | Conn_Coaxial | U.FL_Hirose_U.FL-R-SMT-1_Vertical |  | 1
J3 | Conn_Coaxial | U.FL_Hirose_U.FL-R-SMT-1_Vertical |  | 1
J4 | Conn_01x05_Pin | PinHeader_1x05_P1.27mm_Vertical | C22438102 | 1
J5 | USB4105-GF-A | USB_C_Receptacle_GCT_USB4105-xx-A_16P_TopMnt_Horizontal | C3020560 | 1
J6 | Conn_Coaxial | CONMMCX002-SMD | C22438298 | 1
J7 | Conn_Coaxial | CONMMCX002-SMD | C22438298 | 1
R1 | 5.1k | C_01005_0402Metric | C881131 | 1
R2 | 5.1k | R_01005_0402Metric | C881131 | 1
R3 | 330 ohms | R_0603_1608Metric | C23138 | 1
R4 | 200k | R_01005_0402Metric | C25764 | 1
R5 | 40.2K | R_01005_0402Metric | C100415 | 1
R6 | 0 | R_01005_0402Metric |  | 1
R7 | 0 | R_01005_0402Metric | C60485 | 1
R8 | 0 | R_01005_0402Metric | C60485 | 1
R9 | 0 | R_01005_0402Metric |  | 1
R10 | 22k | R_0603_1608Metric | C881373 | 1
R11 | 187k | R_0603_1608Metric | C22896 | 1
R12 | 12.4k | R_0603_1608Metric | C22865 | 1
U1 | mosaic-G5-P3 | MOSAIC-G3 P3 | C54015208 | 1
U2 | ECMF02-2AMX6 | ST_UQFN-6L_1.5x1.7mm_P0.5mm | C2651144 | 1
U3 | XC8111AA01MR-G | SOT-25_TOR | C3235548 | 1
U7 | XC8111AA01MR-G | SOT-25_TOR | C3235548 | 1
U4 | Teensy | Untitled_1 |  | 1
U5 | TPS7A9401DSCR | DSC0010J-MFG | C5220127 | 1
U8 | MPM3814C | ECLGA-14_MPM3814C_MNP | C6909500 | 1

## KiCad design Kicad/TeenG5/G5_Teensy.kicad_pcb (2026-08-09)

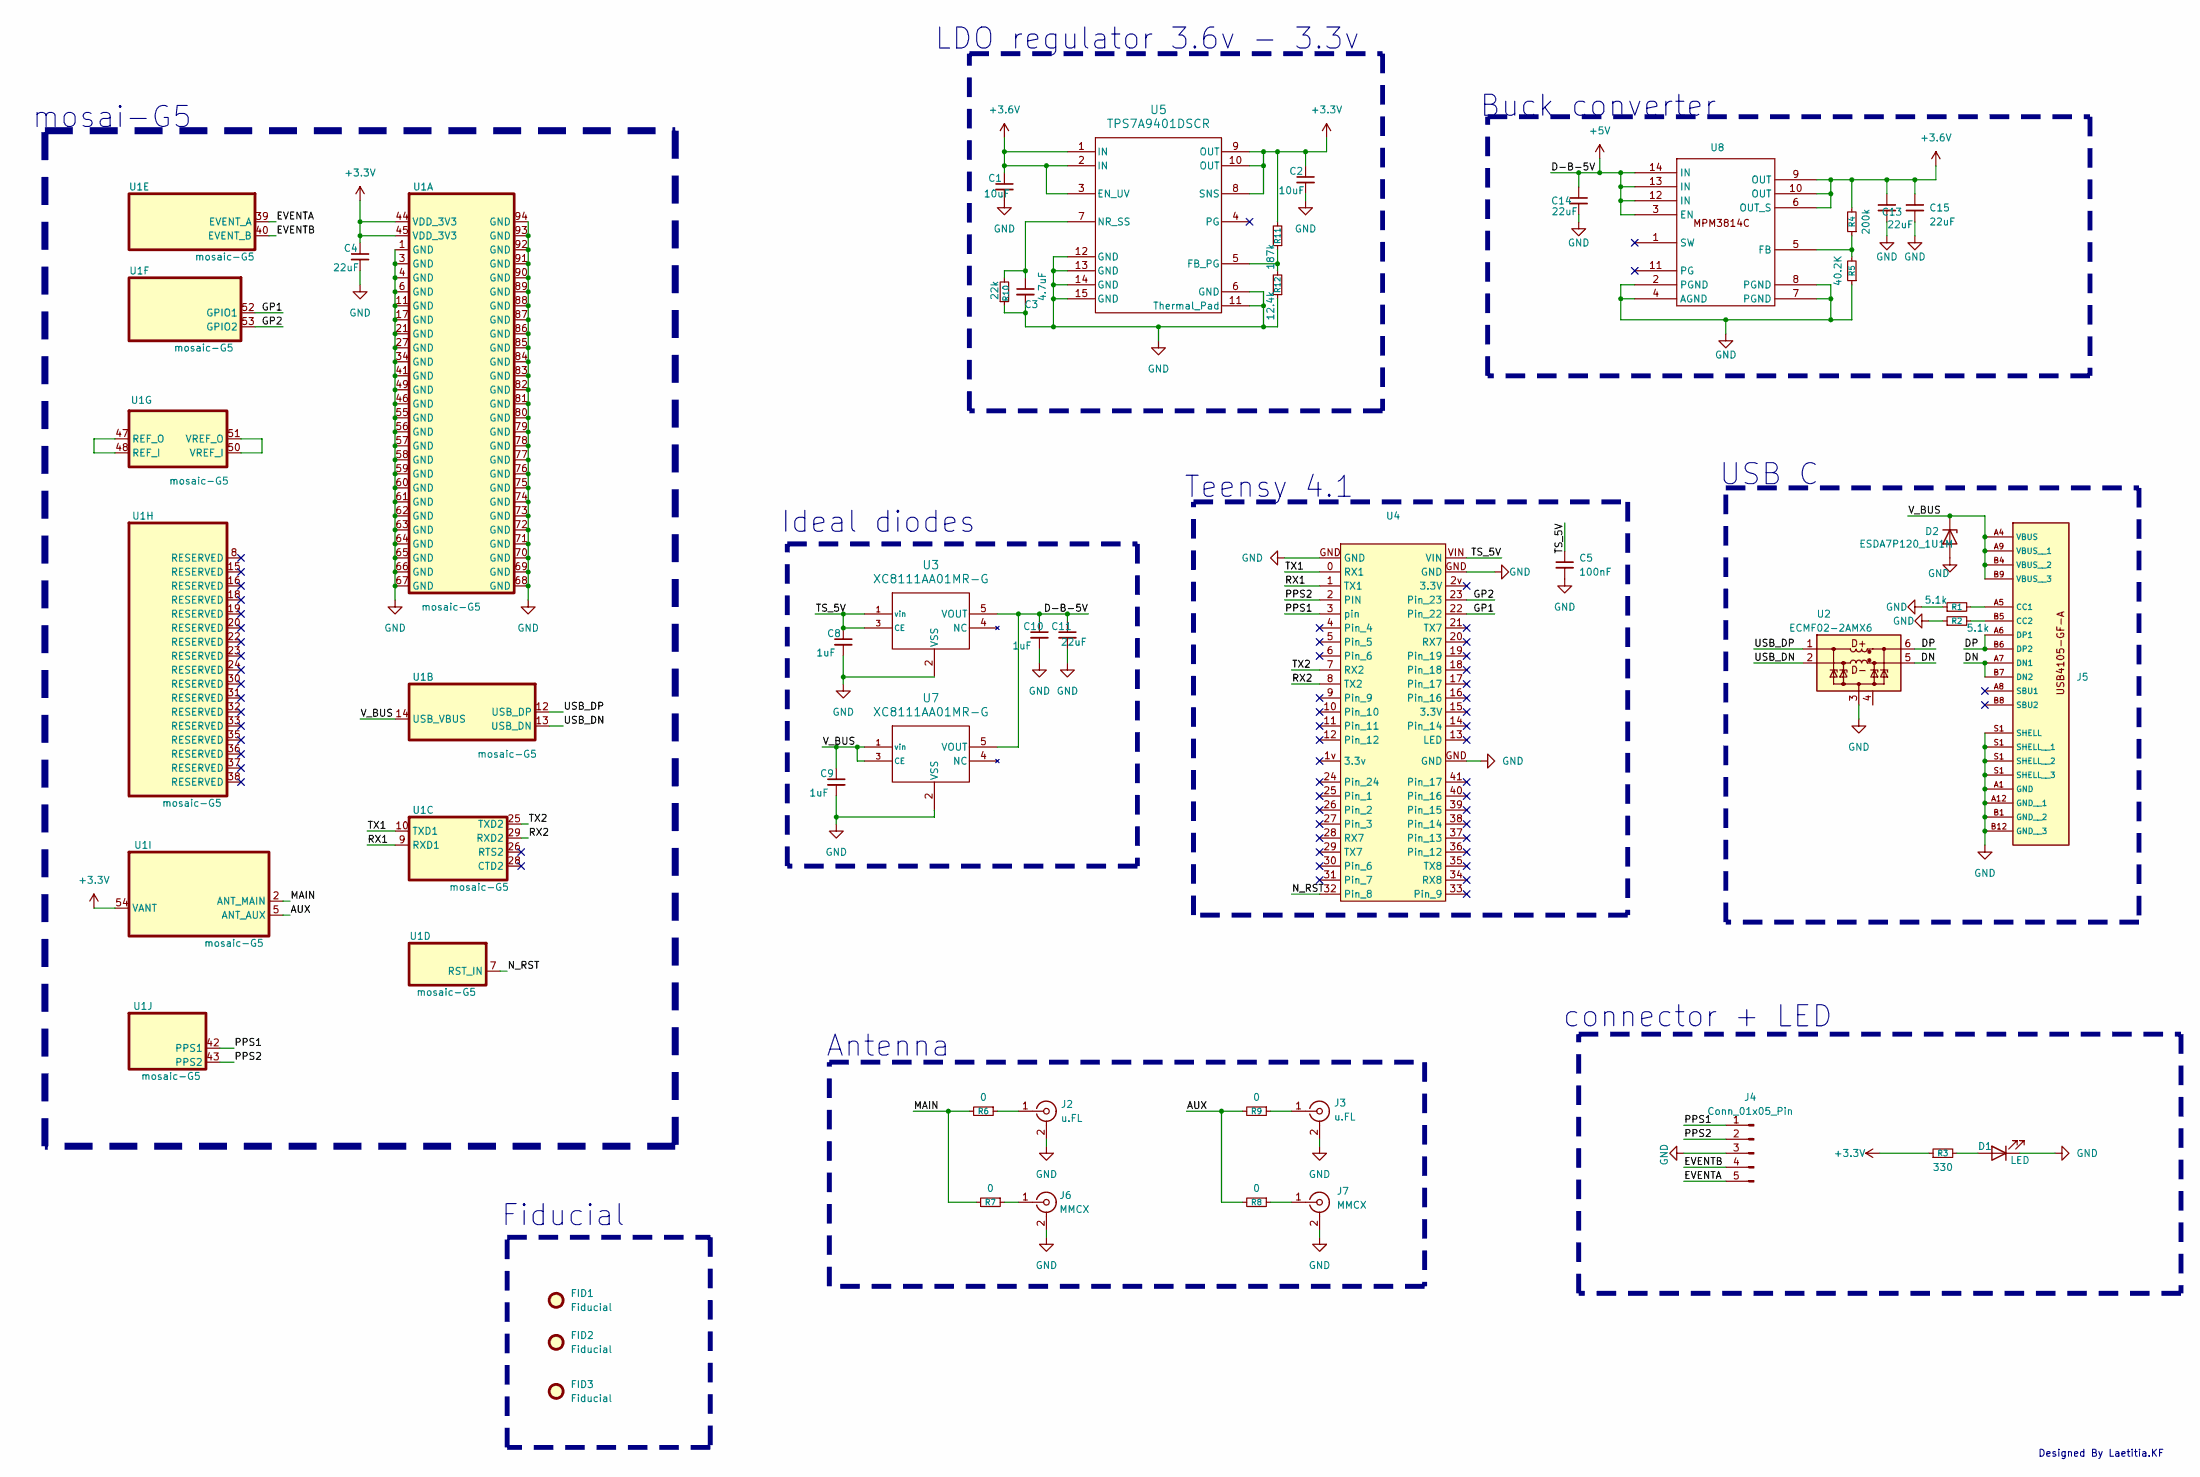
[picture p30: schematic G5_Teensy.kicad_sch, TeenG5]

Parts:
C1, C2: 10uF; C_0603_1608Metric
C3: 4.7uF; C_0603_1608Metric
C4: 22uF; C_0603_1608Metric
C5: 100nF; C_0603_1608Metric
C8, C9, C10: 1uF; C_0603_1608Metric
C11, C13, C14, C15: 22uF; C_0805_2012Metric
D1: LED; LED_0603_1608Metric
D2: ESDA7P120_1U1M; DIODE_ESDA7P120-1U1M_STM
FID1, FID2, FID3: Fiducial; Fiducial_1mm_Mask2mm
J2, J3: u.FL; U.FL_Hirose_U.FL-R-SMT-1_Vertical
J4: Conn_01x05_Pin; PinHeader_1x05_P1.27mm_Vertical
J5: USB_C_Receptacle_GCT_USB4105-xx-A_16P_TopMnt_Horizontal
J6, J7: MMCX; CONMMCX002-SMD
R1: 5.1k; C_0402_1005Metric
R2: 5.1k; R_0402_1005Metric
R3: 330; R_0603_1608Metric
R4: 200k; C_0402_1005Metric
R5: 40.2K; R_0402_1005Metric
R6, R7, R8, R9: 0; R_0402_1005Metric
R10: 22k; R_0603_1608Metric
R11: 187k; R_0603_1608Metric
R12: 12.4k; R_0603_1608Metric
U1: mosaic-G5; LGA54_MOSAIC-MINI_SEP
U2: ECMF02-2AMX6; ST_UQFN-6L_1.5x1.7mm_P0.5mm
U3, U7: XC8111AA01MR-G; SOT-25_TOR
U4: Untitled_1
U5: TPS7A9401DSCR; DSC0010J-MFG
U8: ECLGA-14_MPM3814C_MNP

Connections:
+3.3V: C2.1, C4.1, R3.1, R11.2, U1.44 (VDD_3V3), U1.45 (VDD_3V3), U1.54 (VANT), U5.8 (SNS), U5.9 (OUT), U5.10 (OUT)
+3.6V: C1.1, C13.1, C15.1, R4.2, U5.1 (IN), U5.2 (IN), U5.3 (EN_UV), U8.6 (OUT_S), U8.9 (OUT), U8.10 (OUT)
+5V: C10.1, C11.1, C14.1, U3.5 (VOUT), U7.5 (VOUT), U8.3 (EN), U8.12 (IN), U8.13 (IN), U8.14 (IN)
/AUX: R8.2, R9.2, U1.5 (ANT_AUX)
/DN: J5.A7 (DN1), J5.B7 (DN2), U2.5 (D-_out)
/DP: J5.A6 (DP1), J5.B6 (DP2), U2.6 (D+_out)
/EVENTA: J4.5, U1.39 (EVENT_A)
/EVENTB: J4.4, U1.40 (EVENT_B)
/GP1: U1.52 (GPIO1), U4.22
/GP2: U1.53 (GPIO2), U4.23
/MAIN: R6.2, R7.2, U1.2 (ANT_MAIN)
/N_RST: U1.7 (RST_IN), U4.32 (Pin_8)
/PPS1: J4.1, U1.42 (PPS1), U4.3 (pin)
/PPS2: J4.2, U1.43 (PPS2), U4.2 (PIN)
/RX1: U1.9 (RXD1), U4.1 (TX1)
/RX2: U1.29 (RXD2), U4.8 (TX2)
/TS_5V: C5.1, C8.1, U3.1 (vin), U3.3 (CE), U4.VIN
/TX1: U1.10 (TXD1), U4.0 (RX1)
/TX2: U1.25 (TXD2), U4.7 (RX2)
/USB_DN: U1.13 (USB_DN), U2.2 (D-_in)
/USB_DP: U1.12 (USB_DP), U2.1 (D+_in)
/V_BUS: C9.1, D2.1 (K), J5.A4 (VBUS), J5.A9 (VBUS__1), J5.B4 (VBUS__2), J5.B9 (VBUS__3), U1.14 (USB_VBUS), U7.1 (vin), U7.3 (CE)
GND: C1.2, C2.2, C3.2, C4.2, C5.2, C8.2, C9.2, C10.2, C11.2, C13.2, C14.2, C15.2, D1.1 (K), D2.2 (A), J2.2 (Ext), J3.2 (Ext), J4.3, J5.A1 (GND), J5.A12 (GND__1), J5.B1 (GND__2), J5.B12 (GND__3), J5.S1 (SHELL__2), J6.2 (Ext), J7.2 (Ext), R1.1, R2.1, R5.1, R10.1, R12.1, U1.1 (GND), U1.3 (GND), U1.4 (GND), U1.6 (GND), U1.11 (GND), U1.17 (GND), U1.21 (GND), U1.27 (GND), U1.34 (GND), U1.41 (GND), U1.46 (GND), U1.49 (GND), U1.55 (GND), U1.56 (GND), U1.57 (GND), U1.58 (GND), U1.59 (GND), U1.60 (GND), U1.61 (GND), U1.62 (GND), U1.63 (GND), U1.64 (GND), U1.65 (GND), U1.66 (GND), U1.67 (GND), U1.68 (GND), U1.69 (GND), U1.70 (GND), U1.71 (GND), U1.72 (GND), U1.73 (GND), U1.74 (GND), U1.75 (GND), U1.76 (GND), U1.77 (GND), U1.78 (GND), U1.79 (GND), U1.80 (GND), U1.81 (GND), U1.82 (GND), U1.83 (GND), U1.84 (GND), U1.85 (GND), U1.86 (GND), U1.87 (GND), U1.88 (GND), U1.89 (GND), U1.90 (GND), U1.91 (GND), U1.92 (GND), U1.93 (GND), U1.94 (GND), U2.3 (GND), U3.2 (VSS), U4.GND, U5.6 (GND), U5.11 (Thermal_Pad), U5.12 (GND), U5.13 (GND), U5.14 (GND), U5.15 (GND), U7.2 (VSS), U8.2 (PGND), U8.4 (AGND), U8.7 (PGND), U8.8 (PGND)
unnamed: D1.2 (A), R3.2
unnamed: J2.1 (In), R6.1
unnamed: J3.1 (In), R9.1
unnamed: J5.A5 (CC1), R1.2
unnamed: J5.B5 (CC2), R2.2
unnamed: J6.1 (In), R7.1
unnamed: J7.1 (In), R8.1
unnamed: U1.47 (REF_O), U1.48 (REF_I)
unnamed: U1.50 (VREF_I), U1.51 (VREF_O)
unnamed: R11.1, R12.2, U5.5 (FB_PG)
unnamed: C3.1, R10.2, U5.7 (NR_SS)
unnamed: R4.1, R5.2, U8.5 (FB)

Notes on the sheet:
LDO regulator 3.6v - 3.3v
Teensy 4.1
Buck converter
connector + LED
Fiducial
Antenna
Ideal diodes
mosai-G5
USB C
Designed By Laetitia.KF

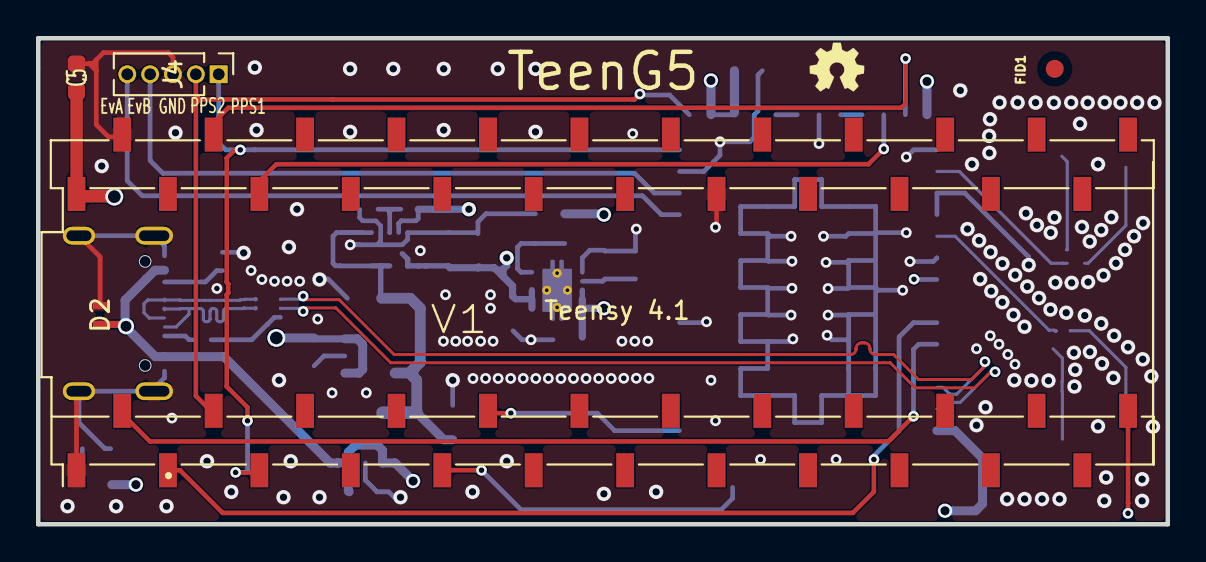
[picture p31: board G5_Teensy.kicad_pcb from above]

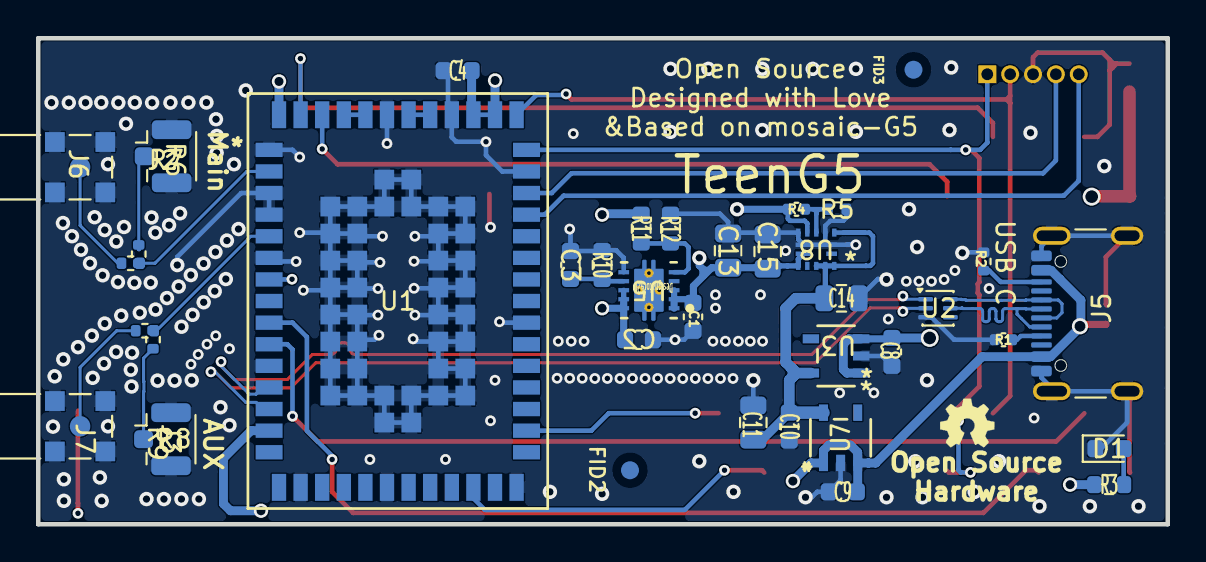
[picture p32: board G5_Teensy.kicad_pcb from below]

Board: 4 copper layers, 62.8 x 27.0 mm, 42 parts (37 on the bottom side), 35 nets.
